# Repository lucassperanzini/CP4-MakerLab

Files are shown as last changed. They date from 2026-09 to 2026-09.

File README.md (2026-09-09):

# Projeto Carrinho — Carrinho"Pokébola"

Projeto de montagem de um carrinho robótico 2WD (duas rodas motorizadas + roda boba), com carenagem esférica impressa em 3D no estilo pokébola.

## Equipe

- Lucas Pisaneschi Speranzini RM98297
- João Pedro de Souza Vieira RM99805

**Laboratório:** Project Maker Lab

## Componentes principais

- ESP32 (controlador)
- Módulo driver de motor L298N
- 2x motor DC com redução 1:48
- Rodas 70x26mm
- Roda boba
- Suporte de pilhas
- Carenagem esférica em PLA (impressa em Bambu Lab A1)
- Chassi em madeira (corte a laser)

---

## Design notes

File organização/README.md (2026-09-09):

# Projeto Carrinho — Carrinho Robótico "Pokébola"

Projeto de montagem de um carrinho robótico 2WD (duas rodas motorizadas + roda boba), com carenagem esférica impressa em 3D no estilo pokébola.

## Equipe

- Lucas
- João

**Laboratório:** Project Maker Lab

## Status atual

- [x] Definição dos requisitos e componentes
- [x] Croqui do chassi
- [x] Carenagem esférica modelada e impressa (base + tampa, encaixe por pressão)
- [x] Chassi interno em madeira (corte a laser) definido
- [x] Diagramas de conexão e alimentação
- [x] MVP, MoSCoW, Backlog, Kanban e planilha de custos definidos
- [ ] Montagem eletrônica completa (ESP32 + L298N + motores)
- [ ] Upload e testes do firmware
- [ ] Testes de locomoção

## Estrutura do repositório

```
├── docs/                          Documentação geral (Parte 1)
│   ├── ficha-requisitos.md
│   ├── croqui-chassi.png
│   ├── mudancas-estrutura-chassi.md
│   ├── conexoes-eletronicas.png
│   ├── diagrama-alimentacao.png
│   └── organizacao-componentes.png
│
├── hardware/                      Parte 2
│   ├── arquitetura/                 imagens e diagramas
│   └── componentes/                 lista-componentes.md
│
├── cad/                            Parte 2
│   ├── STL/
│   │   ├── v0.1/                    primeiro chassi customizado (disco)
│   │   ├── v0.2/                    carenagem oca + colunas internas
│   │   ├── v0.3/                    corte plano + furos das rodas
│   │   └── v0.4-atual/              base + tampa, com encaixe por pressão
│   └── fonte-do-modelo/             scripts Python (trimesh) usados para gerar os STL
│
├── src/                            Parte 2
│   └── codigo.ino                   firmware ESP32 (controle dos motores via L298N)
│
└── organização/                    Planejamento do projeto
    ├── mvp.md                        definição do MVP e da conclusão
    ├── moscow.md                     classificação MoSCoW das funcionalidades
    ├── backlog.md                    tarefas, responsáveis e status
    ├── dependencias.md + .png        mapa de dependências entre tarefas
    ├── kanban.md                     quadro Kanban (snapshot)
    └── planilha-custos.xlsx          custos, lojas, links e quantidades
```

## Documentação (Parte 1)

- [Ficha de Requisitos](./docs/ficha-requisitos.md)
- [Mudanças na estrutura do chassi](./docs/mudancas-estrutura-chassi.md)
- [Conexões dos componentes eletrônicos](./docs/conexoes-eletronicas.png)
- [Diagrama de alimentação](./docs/diagrama-alimentacao.png)
- [Organização dos componentes (fixação e fiação)](./docs/organizacao-componentes.png)

## Organização do projeto

- [MVP — quando estará minimamente funcional / concluído](./organização/mvp.md)
- [Classificação MoSCoW](./organização/moscow.md)
- [Backlog de tarefas](./organização/backlog.md)
- [Mapa de dependências](./organização/dependencias.md)
- [Kanban](./organização/kanban.md)
- [Planilha de custos](./organização/planilha-custos.xlsx)

## Componentes principais

Ver [lista completa](./hardware/componentes/lista-componentes.md) e a [planilha de custos](./organização/planilha-custos.xlsx). Resumo:

- ESP32 (controlador)
- Módulo driver de motor L298N
- 2x motor DC com redução 1:48
- Rodas 70×26mm
- Roda boba
- Suporte de pilhas
- Carenagem esférica em PLA (impressa em Bambu Lab A1)
- Chassi em madeira (corte a laser)

## Modelagem 3D

Os modelos foram gerados de forma paramétrica via scripts Python (biblioteca `trimesh`), no lugar de um software de CAD tradicional (OpenSCAD/Fusion). Os scripts-fonte estão em [`cad/fonte-do-modelo`](./cad/fonte-do-modelo), e os `.stl` versionados em [`cad/STL`](./cad/STL).

## Firmware

Código-fonte em [`src/codigo.ino`](./src/codigo.ino). Pinagem documentada no cabeçalho do arquivo e no [diagrama de conexões](./docs/conexoes-eletronicas.png).

---

*Documentação em construção — próximas atualizações incluirão testes de locomoção e ajustes finais de montagem.*

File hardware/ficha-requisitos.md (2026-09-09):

# Ficha de Requisitos — Carrinho Robótico "Pokébola"

**Projeto:** Carrinho
**Equipe:** Lucas, João
**Turma** 4ESPY
**Disciplina:** Project Maker Lab

---

## 1. Dimensões gerais

| Item | Valor |
|---|---|
| Diâmetro externo da carenagem (esfera) | ~190,5 mm |
| Espessura da parede da carenagem | 6 mm |
| Material da carenagem | PLA (impressão 3D) |
| Altura do corte inferior (para encaixe do chassi) | ~36–40 mm |
| Diâmetro do piso resultante do corte | ~146–150 mm |
| Trilho entre rodas (centro a centro) | 140 mm |
| Diâmetro das rodas | 70 mm |
| Largura das rodas | 26 mm |
| Material do chassi interno | Madeira (corte a laser) |

## 2. Motores

| Item | Especificação |
|---|---|
| Quantidade | 2 |
| Tipo | Motor DC com caixa de redução 1:48 |
| Tensão | 3–6 V |
| Tração | Diferencial (2 rodas motorizadas + 1 roda boba de apoio) |

## 3. Placa controladora e eletrônica

| Componente | Função |
|---|---|
| ESP32 | Controlador principal (lógica, comunicação) |
| Módulo driver L298N | Aciona os motores (ponte H), recebe sinal do ESP32 e energia da bateria |
| Suporte de pilhas | Alimentação do sistema |
| Sensor de Distância | 

## 4. Posição dos componentes

Todos os componentes ficam montados sobre o chassi de madeira, encaixado no piso resultante do corte inferior da carenagem (ver croqui):

- **ESP32**: posição central-frontal do chassi
- **Módulo L298N**: posição central-traseira do chassi
- **Suporte de pilhas**: parte frontal, acima do ESP32
- **Motores DC**: um de cada lado, afastados 70 mm do centro, alinhados aos furos das rodas na carenagem
- **Roda boba**: parte traseira, para equilíbrio do terceiro ponto de apoio

*(posições sujeitas a ajuste fino conforme o layout real da madeira já cortada)*

## 5. Carenagem (cobertura)

- Formato esférico, estilo "pokébola", impressa em duas metades (base + tampa)
- **Base** (metade fixa): contém o corte inferior para o chassi, os furos das rodas e o lábio de encaixe
- **Tampa** (metade removível): contém a ranhura correspondente para o encaixe
- **Método de fechamento**: encaixe por pressão (lábio/ranhura), sem uso de cola — permite abrir para acesso à bateria e eletrônica
- Impressa em impressora Bambu Lab A1 (mesa útil 256×256×256 mm)

## 6. Croqui do chassi

Ver arquivo [`croqui-chassi.png`](./croqui-chassi.png) — vista de cima com posicionamento e cotas.

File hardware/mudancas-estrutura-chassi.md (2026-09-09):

# Mudanças na Estrutura do Chassi

Histórico das decisões de projeto e o motivo de cada mudança.

## v0.1 — Chassi retangular original (kit)
- Kit "Chassi 2 Rodas Base de Acrílico 2WD" (Ref. CF04)
- Base de acrílico 15×21cm, motores DC 1:48, rodas, roda boba
- **Problema:** dimensões grandes demais para caber numa carenagem esférica de tamanho razoável (diagonal de ~26cm exigiria uma esfera de 30cm+)

## v0.2 — Chassi customizado em disco
- Desenhado um chassi circular de 160mm de diâmetro, com furos de fixação para motores, L298N e roda boba
- Objetivo: reduzir o footprint para caber numa esfera menor (~24cm)

## v0.3 — Carenagem esférica oca com colunas internas
- Definido formato "pokébola": duas metades ocas (não maciças), unidas na linha do equador
- Testada a opção de preencher a metade inferior com material sólido → **descartada**: peso estimado de ~9kg, incompatível com o torque dos motores DC 3-6V
- Adotado: casca oca de parede 6mm + colunas de apoio internas para sustentar o chassi
- Carenagem impressa com ~198mm de diâmetro (Bambu Lab A1)

## v0.4 — Corte plano na base + chassi em madeira
- **Mudança de abordagem:** ao invés de um disco de plástico preso por colunas na altura do equador, foi feito um corte plano na parte inferior da esfera (~36–40mm de altura a partir do polo)
- O corte gera um piso plano de ~146–150mm de diâmetro, onde um **chassi de madeira cortado a laser** é encaixado
- **Vantagem:** montagem de motores e componentes fica muito mais simples numa superfície plana do que na parede curva da esfera
- As colunas internas da v0.3 tornaram-se obsoletas e foram removidas do modelo

## v0.5 — Furos das rodas corrigidos
- Verificado que o trilho real entre rodas (140mm) não cabia dentro do buraco central do corte plano (a roda ultrapassava a borda em ~17mm)
- Solução: mantido o buraco central de acesso (para a madeira) e adicionados **2 furos individuais**, um por roda, posicionados exatamente na localização real de cada roda (70mm do centro), cortados na parede curva ao redor do buraco central
- Furos alinhados com o eixo real da roda (não com a direção radial da esfera), eliminando uma pequena interferência residual

## v0.6 — Encaixe por pressão entre as duas metades
- Substituído o encaixe original (peças soltas de dobradiça/botão) por um **lábio de encaixe por pressão** (anel de 2mm) na base, com **ranhura correspondente** na tampa (folga de 0,2mm)
- Permite abrir/fechar sem cola, para acesso à bateria e eletrônica
- A faixa do equador e as peças de botão/dobradiça originais foram fundidas permanentemente na base

## Estado atual
- Base e tampa modeladas e com encaixe validado (0 colisões verificadas)
- Chassi em madeira pronto (corte a laser)
- Próxima etapa: montagem elétrica final e fixação dos componentes na madeira

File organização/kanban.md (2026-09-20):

# Kanban

| 📋 A Fazer | 🔶 Em Andamento | ✅ Concluído |
|---|---|---|
| T05 — Ligar ESP32 → L298N *(Lucas)* | | T01 — Montar chassi de madeira *(Lucas)* |
| T06 — Ligar L298N → motores/bateria *(Lucas)* | | T02 — Modelar/imprimir carenagem *(João)* |
| T07 — Firmware base *(João)* | | T03 — Furos das rodas *(João)* |
| T08 — Testar locomoção *(Lucas + João)* | | T04 — Encaixe base/tampa *(João)* |
| T09 — Fechar e testar na carenagem *(Lucas)* | | |
| T10 — Organizar fiação *(Lucas)* | | |
| T11 — Controle Bluetooth *(João)* | | |
| T12 — Testes de autonomia *(Lucas)* | | |
| T13 — LED de status *(João)* | | |
| T14 — Ajuste PWM *(João)* | | |
| T15 — Acabamento estético *(Lucas)* | | |
| T16 — Documentação final *(Lucas + João)* | | |

**Legenda de responsáveis:** Lucas (montagem mecânica/elétrica) · João (modelagem 3D/firmware) — ver responsabilidades completas no [Backlog](./backlog.md).

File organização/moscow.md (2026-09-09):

# Classificação MoSCoW

| Prioridade | Funcionalidade | Justificativa |
|---|---|---|
| **Must have** | Chassi montado (motores, ESP32, L298N, bateria) | Sem isso não existe carrinho |
| **Must have** | Carenagem fechando (base + tampa) | Requisito estético/estrutural definido no projeto |
| **Must have** | Locomoção básica (frente, trás, girar) via firmware | Núcleo funcional do MVP |
| **Must have** | Alimentação autônoma por bateria | Sem isso o carrinho não é portátil |
| **Should have** | Fiação organizada com abraçadeiras/organizador | Evita curto-circuito e falha mecânica, mas não impede o funcionamento básico |
| **Should have** | Encaixe da tampa testado e confiável (abrir/fechar repetidas vezes) | Importante para manutenção, mas o MVP pode rodar com a tampa presa provisoriamente |
| **Should have** | Controle remoto via Bluetooth (ESP32 já suporta nativamente) | Eleva bastante a usabilidade, mas não é bloqueante pro MVP |
| **Could have** | Indicador visual (LED) de status (ligado/bateria baixa) | Boa prática de UX, mas dispensável |
| **Could have** | Ajuste fino de velocidade via PWM (controle de aceleração suave) | Melhoria de qualidade de movimento |
| **Could have** | Pintura/acabamento estético fiel às cores da pokébola | Estética, não afeta funcionamento |
| **Won't have (por ora)** | Recarga automática / base de carregamento | Fora do escopo |
| **Won't have (por ora)** | Câmera ou sensores de visão | Fora do escopo |

Ver o cruzamento dessas prioridades com o cronograma em [Backlog](./backlog.md) e [Kanban](./kanban.md).

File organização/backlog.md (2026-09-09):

# Backlog

**Divisão de responsabilidades:**
- **Lucas** — software (firmware) e modelagem 3D (CAD)
- **João** — montagem física do chassi e da eletrônica

*(Exceção: LED, sensor de distância e buzzer já foram ligados no ESP32 pelo próprio Lucas — mantidos com ele por ser o que realmente aconteceu.)*

| ID | Tarefa | Responsável | MoSCoW | Depende de | Status |
|---|---|---|---|---|---|
| T01 | Montar chassi de madeira com motores fixados | João | Must | — | ✅ Concluído |
| T02 | Modelar e imprimir carenagem (base + tampa) | Lucas | Must | — | ✅ Concluído |
| T03 | Cortar furos das rodas na carenagem | Lucas | Must | T02 | ✅ Concluído |
| T04 | Projetar e validar encaixe por pressão base/tampa | Lucas | Should | T02 | ✅ Concluído |
| T05 | Ligar ESP32 ao L298N (fiação de sinal) | João | Must | T01 | ⬜ A fazer |
| T06 | Ligar L298N aos motores e à bateria | João | Must | T01, T05 | ⬜ A fazer |
| T07 | Escrever firmware base (andar frente/trás/girar) | Lucas | Must | T05, T06 | ⬜ A fazer |
| T08 | Testar locomoção com a eletrônica solta (fora da carenagem) | Lucas + João | Must | T07 | ⬜ A fazer |
| T09 | Fechar tudo dentro da carenagem e testar encaixe final | João | Must | T04, T08 | ⬜ A fazer |
| T10 | Organizar fiação interna (abraçadeiras/organizador) | João | Should | T06 | ⬜ A fazer |
| T11 | Implementar controle via Bluetooth | Lucas | Should | T07 | ⬜ A fazer |
| T12 | Testes de autonomia de bateria | João | Should | T09 | ⬜ A fazer |
| T13 | Ligar LED indicador de status no ESP32 | Lucas | Could | T05 | ✅ Concluído |
| T14 | Ajuste fino de velocidade (PWM suave) | Lucas | Could | T07 | ⬜ A fazer |
| T15 | Acabamento estético da carenagem (pintura) | João | Could | T09 | ⬜ A fazer |
| T16 | Atualizar documentação final do repositório | Lucas + João | Must | T09, T11 | ⬜ A fazer |
| T17 | Ligar sensor de distância no ESP32 | Lucas | Could | T05 | ✅ Concluído |
| T18 | Ligar buzzer no ESP32 | Lucas | Could | T05 | ✅ Concluído |

**Status usados:** ⬜ A fazer · 🔶 Em andamento · ✅ Concluído

Ver o quadro visual em [Kanban](./kanban.md) e o mapeamento de dependências em [Dependências](./dependencias.md).

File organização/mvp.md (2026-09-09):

# MVP — Produto Mínimo Viável

## Quando o carrinho estará minimamente funcional (MVP)

O MVP é considerado atingido quando:

- [ ] Chassi de madeira montado com os 2 motores, ESP32, L298N e suporte de pilhas fixados
- [ ] Firmware carregado no ESP32 fazendo o carrinho andar para frente, para trás e girar (comando pré-programado, sem controle remoto)
- [ ] Alimentação por bateria funcionando de forma independente (sem precisar de USB conectado ao PC)
- [ ] Rodas tocando o chão corretamente, sem a carenagem raspar no chão

**Em resumo:** o carrinho se movimenta de forma autônoma, fechado dentro da carenagem, mesmo que o "controle" seja só uma sequência de movimentos fixa no código.

## Quando o projeto estará concluído

- [ ] Tudo o que está no MVP, +
- [ ] Alguma forma de controle em tempo real (Bluetooth, Wi-Fi/app, ou controle remoto simples)
- [ ] Fiação interna organizada e presa (abraçadeiras/organizador — ver [organização dos componentes](../docs/organizacao-componentes.png))
- [ ] Encaixe da tampa testado múltiplas vezes sem folga excessiva nem dificuldade de abrir
- [ ] Documentação do repositório completa e atualizada (README, ficha de requisitos, diagramas, backlog)

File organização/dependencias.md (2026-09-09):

# Dependências entre Tarefas

Mapa de dependências

## Caminho crítico (sequência que mais trava o projeto)

```
T01 (chassi) → T05 (ESP32↔L298N) → T06 (L298N↔motores/bateria) → T07 (firmware) → T08 (teste solto) → T09 (fechar na carenagem) → T16 (documentação final)
```

Esse é o caminho que define o prazo mínimo possível: nenhuma tarefa dele pode começar antes da anterior terminar.

## Tarefas que podem rodar em paralelo

- **T02 → T03 → T04** (modelagem/impressão da carenagem) não depende de nada da linha elétrica — pode ser feito ao mesmo tempo que T01, T05, T06
- **T11 (Bluetooth)** só depende do firmware base (T07), não precisa esperar a carenagem estar fechada (T09)
- **T13, T14, T15** (itens "Could have") não bloqueiam nada — podem ficar para o final ou ser cortados sem afetar o restante

## Risco de atraso

O ponto mais sensível é **T09** (fechar tudo dentro da carenagem), porque depende tanto da linha elétrica (T08) quanto da linha mecânica (T04) terminarem. Se uma das duas atrasar, T09 atrasa junto — e com ela, toda a documentação final (T16).

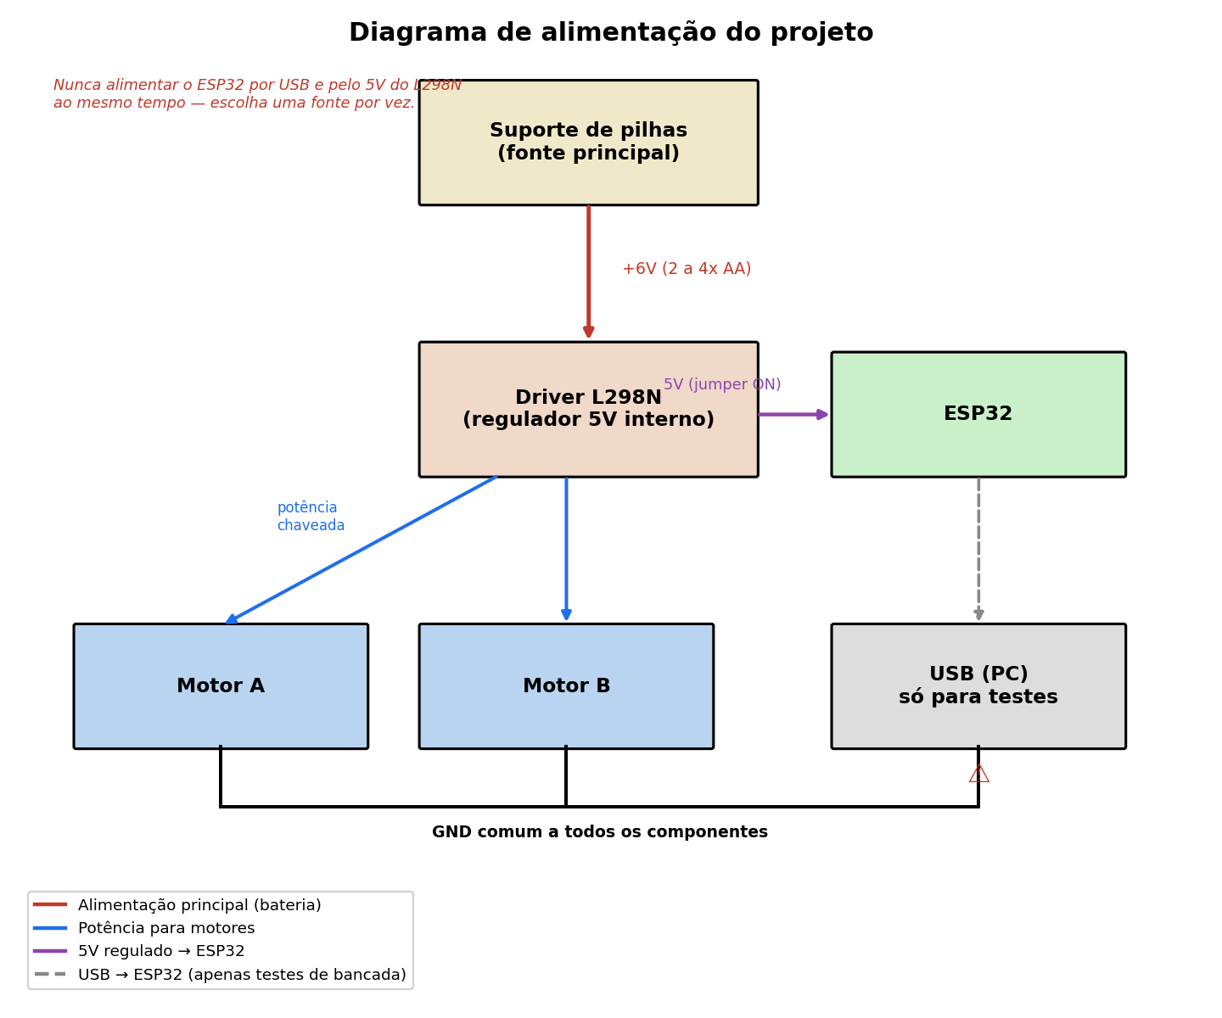
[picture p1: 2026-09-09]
hardware/diagrama-alimentacao.png

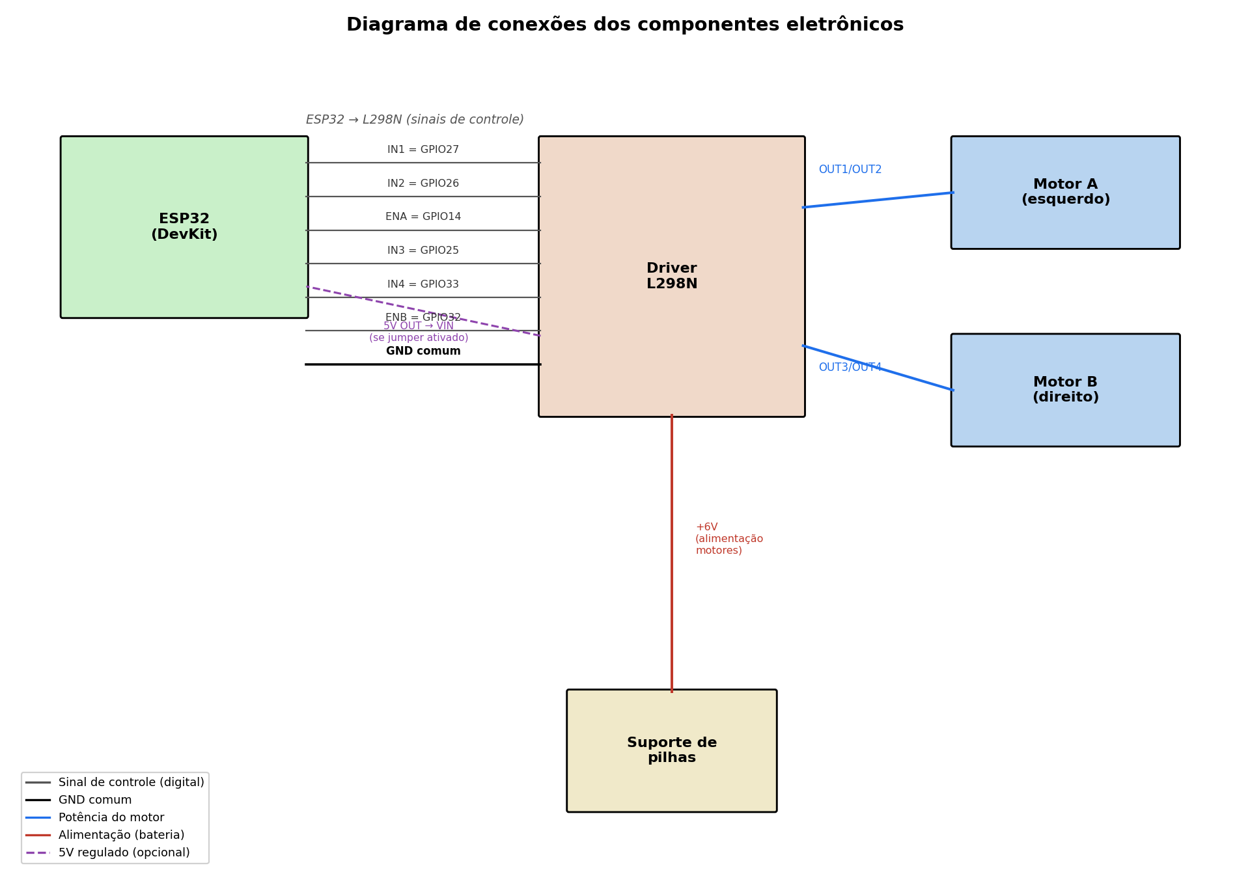
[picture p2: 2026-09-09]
hardware/conexoes-eletronicas.png

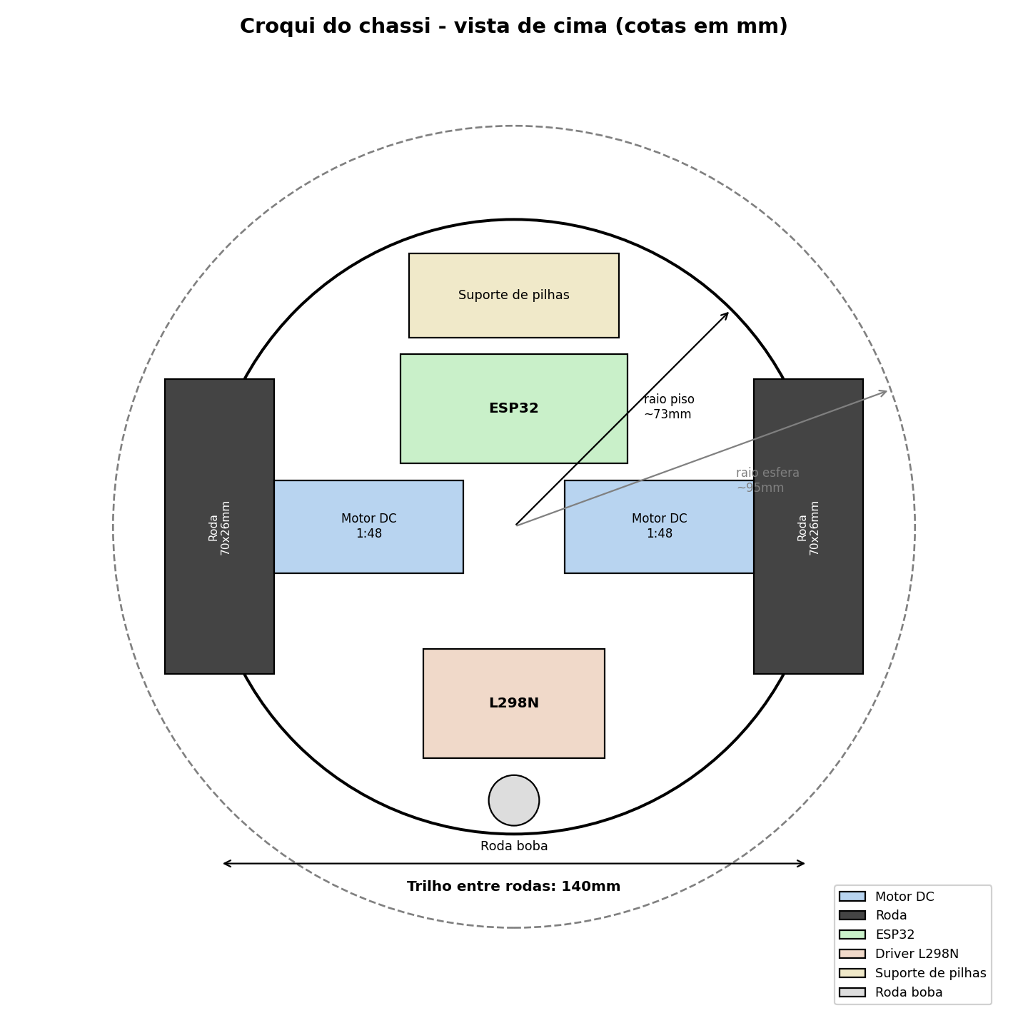
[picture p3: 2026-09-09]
croqui-chassi.png

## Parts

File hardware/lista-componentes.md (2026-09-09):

# Lista de Componentes Utilizados

| # | Componente | Especificação | Quantidade |
|---|---|---|---|
| 1 | Microcontrolador | ESP32 (DevKit) | 1 |
| 2 | Driver de motor | Módulo L298N (ponte H dupla) | 1 |
| 3 | Motor DC | Com caixa de redução 1:48, 3–6V | 2 |
| 4 | Roda | 70mm diâmetro × 26mm largura, borracha | 2 |
| 5 | Roda boba (caster) | Apoio de giro livre | 1 |
| 6 | Suporte de pilhas | Alimentação do sistema | 1 |
| 7 | Chassi interno | Madeira, corte a laser | 1 |
| 8 | Carenagem — base | PLA impresso em 3D (Bambu Lab A1), ~190mm Ø, parede 6mm | 1 |
| 9 | Carenagem — tampa | PLA impresso em 3D (Bambu Lab A1), com ranhura de encaixe | 1 |
| 10 | Cabos/jumpers | Conexão ESP32 ↔ L298N ↔ motores | conforme necessário |
| 11 | Abraçadeiras (zip ties) | Organização e fixação de fios | conforme necessário |

## Origem dos componentes mecânicos
Kit original: "Chassi 2 Rodas Base de Acrílico 2WD + Suporte de Pilhas" (Ref. CF04, Casa da Robótica) — motores, rodas e roda boba reaproveitados do kit; chassi de acrílico original substituído por chassi de madeira sob medida (ver [mudanças na estrutura do chassi](../../docs/mudancas-estrutura-chassi.md)).

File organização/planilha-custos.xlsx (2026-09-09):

Item | Loja | Link | Preço Unit. (R$) | Qtd. | Subtotal (R$) | Observação
ESP32 DevKit (30 pinos) | Saravati | https://www.saravati.com.br/placa-esp32-wifi-bluetooth-devkit-v1-30-pinos.html | R$59.90 | 1 | R$59.90 | Preço confirmado no site em set/2026
Driver Ponte H L298N | LIG Imports | https://www.ligimports.com.br/produto/modulo-ponte-h-l298n/ | R$34.90 | 1 | R$34.90 | Preço confirmado no site em set/2026
Kit Chassi 2 Rodas + Suporte Pilhas (Ref. CF04) | Casa da Robótica | https://www.casadarobotica.com/robotica/chassi-s/carros/kit-chassi-2-rodas | R$59.99 | 1 | R$59.99 | Motores, rodas e roda boba reaproveitados; chassi acrílico substituído pela madeira
Filamento PLA 1kg (para carenagem) | Beehive 3D | https://beehive.com.br/filamentos/ | R$109.90 | 1 | R$109.90 | Usa-se só uma fração do rolo (~300-400g); custo do rolo inteiro listado
Kit Jumpers Macho-Fêmea 40un 20cm | Fermarc | https://www.fermarc.com/kit-jumper-macho-femea-x40-unidades-20cm-para-arduino | R$9.50 | 1 | R$9.50 | Preço confirmado no site em set/2026
Pilhas alcalinas AA (jogo com 4) | Estimado (mercado geral) | https://lista.mercadolivre.com.br/pilha-aa-alcalina | R$14.90 | 1 | R$14.90 | Preço estimado, não coletado de uma página específica
Abraçadeiras de nylon (pacote c/ 100, variadas) | Estimado (mercado geral) | https://lista.mercadolivre.com.br/abracadeira-nylon-kit | R$9.90 | 1 | R$9.90 | Preço estimado, não coletado de uma página específica
Placa de madeira p/ corte a laser (chassi) | Estimado (marcenaria/loja local) | — | R$15.00 | 1 | R$15.00 | Preço estimado; depende do fornecedor de corte a laser usado pela equipe
Parafusos/porcas M3 (kit variado) | Estimado (mercado geral) | https://lista.mercadolivre.com.br/kit-parafuso-m3 | R$12.90 | 1 | R$12.90 | Preço estimado, não coletado de uma página específica
TOTAL ESTIMADO |  |  |  |  | R$326.89
Legenda:
Azul = preço confirmado em loja real (com link)
Azul itálico = preço estimado (sem página específica de origem)
Preços coletados em setembro/2026 — sujeitos a alteração pelas lojas

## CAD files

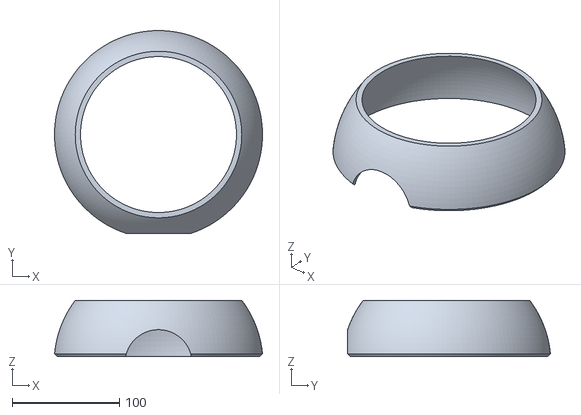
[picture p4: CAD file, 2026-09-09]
stl/baixo.stl
194.2 x 189.4 x 52.7

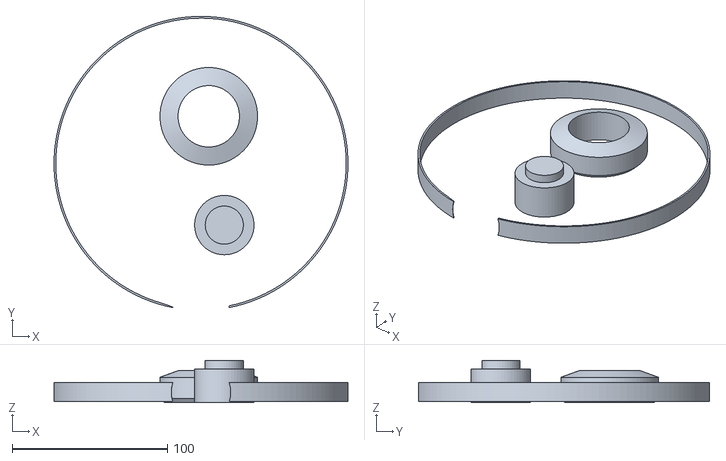
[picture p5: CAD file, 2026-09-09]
stl/Centro.stl
189.1 x 187.4 x 27.3

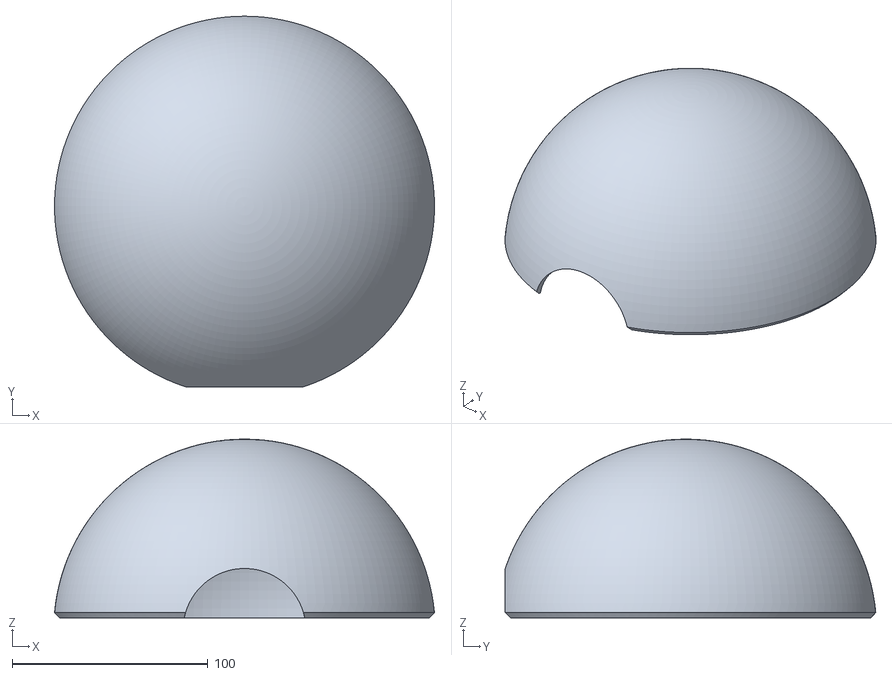
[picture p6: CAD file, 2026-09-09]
stl/cima.stl
194.2 x 189.4 x 91.4

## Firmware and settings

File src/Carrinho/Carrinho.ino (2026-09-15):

#include <BLEDevice.h>
#include <BLEUtils.h>
#include <BLEServer.h>
#include <esp_mac.h>

// Definição dos pinos do sensor ultrassônico e LED
#define TRIG_PIN 5
#define ECHO_PIN 4
#define BUZZER_PIN 18  // Pino do Buzzer
#define LED 2          // Pino do LED azul integrado

// =========================================================================
// MAPEAMENTO DOS PINOS DOS MOTORES (Passe essa lista para o seu amigo!)
// =========================================================================
const int MOTOR_ESQ_1 = 12; // Pino D12 ➔ Entrada IN1 do Driver
const int MOTOR_ESQ_2 = 13; // Pino D13 ➔ Entrada IN2 do Driver
const int MOTOR_DIR_1 = 14; // Pino D14 ➔ Entrada IN3 do Driver
const int MOTOR_DIR_2 = 27; // Pino D27 ➔ Entrada IN4 do Driver

long duracao;
float distancia;

bool tocarMusica = false;

#define SERVICE_UUID        "4FAFC201-1FB5-459E-8FCC-C5C9C331914B"
#define CHARACTERISTIC_UUID "BEB5483E-36E1-4688-B7F5-EA07361B26A8"

BLECharacteristic *pCharacteristic;

// =========================================================================
// FUNÇÕES DE MOVIMENTAÇÃO DO CARRINHO
// =========================================================================
void frente() {
  digitalWrite(MOTOR_ESQ_1, HIGH);  digitalWrite(MOTOR_ESQ_2, LOW);
  digitalWrite(MOTOR_DIR_1, HIGH);  digitalWrite(MOTOR_DIR_2, LOW);
}

void tras() {
  digitalWrite(MOTOR_ESQ_1, LOW);   digitalWrite(MOTOR_ESQ_2, HIGH);
  digitalWrite(MOTOR_DIR_1, LOW);   digitalWrite(MOTOR_DIR_2, HIGH);
}

void esquerda() {
  digitalWrite(MOTOR_ESQ_1, LOW);   digitalWrite(MOTOR_ESQ_2, HIGH); // Roda esquerda para trás
  digitalWrite(MOTOR_DIR_1, HIGH);  digitalWrite(MOTOR_DIR_2, LOW);  // Roda direita para frente
}

void direita() {
  digitalWrite(MOTOR_ESQ_1, HIGH);  digitalWrite(MOTOR_ESQ_2, LOW);  // Roda esquerda para frente
  digitalWrite(MOTOR_DIR_1, LOW);   digitalWrite(MOTOR_DIR_2, HIGH); // Roda direita para trás
}

void parar() {
  digitalWrite(MOTOR_ESQ_1, LOW);   digitalWrite(MOTOR_ESQ_2, LOW);
  digitalWrite(MOTOR_DIR_1, LOW);   digitalWrite(MOTOR_DIR_2, LOW);
}

void efeitoArcadeStart() {
  tone(BUZZER_PIN, 1319, 150); // Nota Mi (E6)
  delay(150);
  tone(BUZZER_PIN, 1568, 150); // Nota Sol (G6)
  delay(150);
  tone(BUZZER_PIN, 2093, 150); // Nota Dó (C7)
  delay(150);
  tone(BUZZER_PIN, 2637, 300); // Nota Mi de novo (E7) - mais longa
  delay(300);
  noTone(BUZZER_PIN);          // Desliga o som
}



// =========================================================================
// LEITURA DE COMANDOS ENVIADOS PELO IPHONE (MAPPED GAMEPAD VIA TEXT)
// =========================================================================
class MyCallbacks: public BLECharacteristicCallbacks {
    void onWrite(BLECharacteristic *pCharacteristic) {
      String value = pCharacteristic->getValue();

      if (value.length() > 0) {
        char comando = value[0]; // Pega a primeira letra enviada pelo app
        
        switch (comando) {
          case 'F': case 'f': frente();   break; // F = Frente
          case 'B': case 'b': tras();     break; // B = Trás (Back)
          case 'L': case 'l': esquerda(); break; // L = Esquerda (Left)
          case 'R': case 'r': direita();  break; // R = Direita (Right)
          case 'S': case 's': parar();    break; // S = Parar (Stop)
          
          // Mantém o teste do LED azul se você quiser piscar para testar
        case '1': 
            digitalWrite(LED, HIGH);
            tocarMusica = true; // Apenas ativa o gatilho, sem travar aqui!
            break;

          case '2': 
            digitalWrite(LED, LOW);
            tocarMusica = false; // Desativa se o comando for recebido
            break;
          
          default: parar(); break;
        }
      }
    }
};

void setup() {
  Serial.begin(115200); // Inicializa a comunicação serial com o computador
  delay(500);           // Pausa para deixar o monitor estável
  
  // Configuração dos Pinos como Saídas e Entradas
  pinMode(LED, OUTPUT);           
  pinMode(TRIG_PIN, OUTPUT);    
  pinMode(ECHO_PIN, INPUT);     
  pinMode(BUZZER_PIN, OUTPUT);  
  
  pinMode(MOTOR_ESQ_1, OUTPUT); pinMode(MOTOR_ESQ_2, OUTPUT);
  pinMode(MOTOR_DIR_1, OUTPUT); pinMode(MOTOR_DIR_2, OUTPUT);
  
  parar(); // Garante que o carrinho comece totalmente parado por segurança

  // Inicialização do Bluetooth BLE
  BLEDevice::init("ESP32_iPhone");
  BLEServer *pServer = BLEDevice::createServer();

  BLEService *pService = pServer->createService(SERVICE_UUID);
  pCharacteristic = pService->createCharacteristic(
                      CHARACTERISTIC_UUID,
                      BLECharacteristic::PROPERTY_READ |
                      BLECharacteristic::PROPERTY_WRITE
                    );

  pCharacteristic->setCallbacks(new MyCallbacks());
  pService->start();

  BLEAdvertising *pAdvertising = BLEDevice::getAdvertising();
  pAdvertising->addServiceUUID(SERVICE_UUID);
  pAdvertising->setScanResponse(true);
  pAdvertising->setMinPreferred(0x06);  
  pAdvertising->setMinPreferred(0x12);
  BLEDevice::startAdvertising();

  Serial.println("ESP32 Inicializado com sucesso! Pronto para o Carrinho 2WD.");
}

void loop() {

  // A execução da música acontece no loop principal
  if (tocarMusica) {
    // fireRed1(BUZZER_PIN,LED);
    // delay(1000);
    // fireRedIntro(BUZZER_PIN,LED);
    // delay(500);
    Hobbit(BUZZER_PIN,LED);
    delay(1000);

    efeitoArcadeStart();
    
    tocarMusica = false; // Desliga o gatilho ao terminar a música


    delay(200);
    digitalWrite(LED, LOW);
      delay(100);
    digitalWrite(LED, HIGH);
      delay(200);
        digitalWrite(LED, LOW);
           delay(200);
        digitalWrite(LED, HIGH);

  }
  // =========================================================================
  // LEITURA DO SENSOR ULTRASSÔNICO E BUZZER
  // =========================================================================
  digitalWrite(TRIG_PIN, LOW);
  delayMicroseconds(2);
  digitalWrite(TRIG_PIN, HIGH);
  delayMicroseconds(10);
  digitalWrite(TRIG_PIN, LOW);

  // CORREÇÃO: Adicionado timeout de 20000ms para o sensor não congelar a recepção do Bluetooth
  duracao = pulseIn(ECHO_PIN, HIGH, 20000); 
  distancia = duracao * 0.034 / 2;

  // Mostra os valores obtidos no Monitor Serial do Windows

  if(distancia != 0){
    Serial.print("Distancia: ");
    Serial.print(distancia);
    Serial.println(" cm");

  }


  // Alerta de proximidade do obstáculo (Garante o aviso e proteção)
  if (distancia > 0 && distancia <= 5) {
    Serial.println("TA PERTO");
    tone(BUZZER_PIN, 3000); 
    
    // SISTEMA DE SEGURANÇA ANTIBATIDA:
    // Se o sensor detectar algo menor ou igual a 5cm, força o carrinho a PARAR
    parar(); 
  } else {
    noTone(BUZZER_PIN);     
  }

  delay(50); // Delay ideal para leitura contínua e manter os controles rápidos
}

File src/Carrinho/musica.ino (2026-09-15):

/* 
  Super Mario Bros - Overworld theme 
  Connect a piezo buzzer or speaker to pin 11 or select a new pin.
  More songs available at https://github.com/robsoncouto/arduino-songs                                            
                                              
                                              Robson Couto, 2019
*/

#define NOTE_B0  31
#define NOTE_C1  33
#define NOTE_CS1 35
#define NOTE_D1  37
#define NOTE_DS1 39
#define NOTE_E1  41
#define NOTE_F1  44
#define NOTE_FS1 46
#define NOTE_G1  49
#define NOTE_GS1 52
#define NOTE_A1  55
#define NOTE_AS1 58
#define NOTE_B1  62
#define NOTE_C2  65
#define NOTE_CS2 69
#define NOTE_D2  73
#define NOTE_DS2 78
#define NOTE_E2  82
#define NOTE_F2  87
#define NOTE_FS2 93
#define NOTE_G2  98
#define NOTE_GS2 104
#define NOTE_A2  110
#define NOTE_AS2 117
#define NOTE_B2  123
#define NOTE_C3  131
#define NOTE_CS3 139
#define NOTE_D3  147
#define NOTE_DS3 156
#define NOTE_E3  165
#define NOTE_F3  175
#define NOTE_FS3 185
#define NOTE_G3  196
#define NOTE_GS3 208
#define NOTE_A3  220
#define NOTE_AS3 233
#define NOTE_B3  247
#define NOTE_C4  262
#define NOTE_CS4 277
#define NOTE_D4  294
#define NOTE_DS4 311
#define NOTE_E4  330
#define NOTE_F4  349
#define NOTE_FS4 370
#define NOTE_G4  392
#define NOTE_GS4 415
#define NOTE_A4  440
#define NOTE_AS4 466
#define NOTE_B4  494
#define NOTE_C5  523
#define NOTE_CS5 554
#define NOTE_D5  587
#define NOTE_DS5 622
#define NOTE_E5  659
#define NOTE_F5  698
#define NOTE_FS5 740
#define NOTE_G5  784
#define NOTE_GS5 831
#define NOTE_A5  880
#define NOTE_AS5 932
#define NOTE_B5  988
#define NOTE_C6  1047
#define NOTE_CS6 1109
#define NOTE_D6  1175
#define NOTE_DS6 1245
#define NOTE_E6  1319
#define NOTE_F6  1397
#define NOTE_FS6 1480
#define NOTE_G6  1568
#define NOTE_GS6 1661
#define NOTE_A6  1760
#define NOTE_AS6 1865
#define NOTE_B6  1976
#define NOTE_C7  2093
#define NOTE_CS7 2217
#define NOTE_D7  2349
#define NOTE_DS7 2489
#define NOTE_E7  2637
#define NOTE_F7  2794
#define NOTE_FS7 2960
#define NOTE_G7  3136
#define NOTE_GS7 3322
#define NOTE_A7  3520
#define NOTE_AS7 3729
#define NOTE_B7  3951
#define NOTE_C8  4186
#define NOTE_CS8 4435
#define NOTE_D8  4699
#define NOTE_DS8 4978
#define REST      0


// change this to make the song slower or faster
int tempo = 200;



// notes of the moledy followed by the duration.
// a 4 means a quarter note, 8 an eighteenth , 16 sixteenth, so on
// !!negative numbers are used to represent dotted notes,
// so -4 means a dotted quarter note, that is, a quarter plus an eighteenth!!
int melody[] = {

  // Super Mario Bros theme
  // Score available at https://musescore.com/user/2123/scores/2145
  // Theme by Koji Kondo
  
  
  NOTE_E5,8, NOTE_E5,8, REST,8, NOTE_E5,8, REST,8, NOTE_C5,8, NOTE_E5,8, //1
  NOTE_G5,4, REST,4, NOTE_G4,8, REST,4, 
  NOTE_C5,-4, NOTE_G4,8, REST,4, NOTE_E4,-4, // 3
  NOTE_A4,4, NOTE_B4,4, NOTE_AS4,8, NOTE_A4,4,
  NOTE_G4,-8, NOTE_E5,-8, NOTE_G5,-8, NOTE_A5,4, NOTE_F5,8, NOTE_G5,8,
  REST,8, NOTE_E5,4,NOTE_C5,8, NOTE_D5,8, NOTE_B4,-4,
  NOTE_C5,-4, NOTE_G4,8, REST,4, NOTE_E4,-4, // repeats from 3
  NOTE_A4,4, NOTE_B4,4, NOTE_AS4,8, NOTE_A4,4,
  NOTE_G4,-8, NOTE_E5,-8, NOTE_G5,-8, NOTE_A5,4, NOTE_F5,8, NOTE_G5,8,
  REST,8, NOTE_E5,4,NOTE_C5,8, NOTE_D5,8, NOTE_B4,-4,

  
  REST,4, NOTE_G5,8, NOTE_FS5,8, NOTE_F5,8, NOTE_DS5,4, NOTE_E5,8,//7
  REST,8, NOTE_GS4,8, NOTE_A4,8, NOTE_C4,8, REST,8, NOTE_A4,8, NOTE_C5,8, NOTE_D5,8,
  REST,4, NOTE_DS5,4, REST,8, NOTE_D5,-4,
  NOTE_C5,2, REST,2,

  REST,4, NOTE_G5,8, NOTE_FS5,8, NOTE_F5,8, NOTE_DS5,4, NOTE_E5,8,//repeats from 7
  REST,8, NOTE_GS4,8, NOTE_A4,8, NOTE_C4,8, REST,8, NOTE_A4,8, NOTE_C5,8, NOTE_D5,8,
  REST,4, NOTE_DS5,4, REST,8, NOTE_D5,-4,
  NOTE_C5,2, REST,2,

  NOTE_C5,8, NOTE_C5,4, NOTE_C5,8, REST,8, NOTE_C5,8, NOTE_D5,4,//11
  NOTE_E5,8, NOTE_C5,4, NOTE_A4,8, NOTE_G4,2,

  NOTE_C5,8, NOTE_C5,4, NOTE_C5,8, REST,8, NOTE_C5,8, NOTE_D5,8, NOTE_E5,8,//13
  REST,1, 
  NOTE_C5,8, NOTE_C5,4, NOTE_C5,8, REST,8, NOTE_C5,8, NOTE_D5,4,
  NOTE_E5,8, NOTE_C5,4, NOTE_A4,8, NOTE_G4,2,
  NOTE_E5,8, NOTE_E5,8, REST,8, NOTE_E5,8, REST,8, NOTE_C5,8, NOTE_E5,4,
  NOTE_G5,4, REST,4, NOTE_G4,4, REST,4, 
  NOTE_C5,-4, NOTE_G4,8, REST,4, NOTE_E4,-4, // 19
  
  NOTE_A4,4, NOTE_B4,4, NOTE_AS4,8, NOTE_A4,4,
  NOTE_G4,-8, NOTE_E5,-8, NOTE_G5,-8, NOTE_A5,4, NOTE_F5,8, NOTE_G5,8,
  REST,8, NOTE_E5,4, NOTE_C5,8, NOTE_D5,8, NOTE_B4,-4,

  NOTE_C5,-4, NOTE_G4,8, REST,4, NOTE_E4,-4, // repeats from 19
  NOTE_A4,4, NOTE_B4,4, NOTE_AS4,8, NOTE_A4,4,
  NOTE_G4,-8, NOTE_E5,-8, NOTE_G5,-8, NOTE_A5,4, NOTE_F5,8, NOTE_G5,8,
  REST,8, NOTE_E5,4, NOTE_C5,8, NOTE_D5,8, NOTE_B4,-4,

  NOTE_E5,8, NOTE_C5,4, NOTE_G4,8, REST,4, NOTE_GS4,4,//23
  NOTE_A4,8, NOTE_F5,4, NOTE_F5,8, NOTE_A4,2,
  NOTE_D5,-8, NOTE_A5,-8, NOTE_A5,-8, NOTE_A5,-8, NOTE_G5,-8, NOTE_F5,-8,
  
  NOTE_E5,8, NOTE_C5,4, NOTE_A4,8, NOTE_G4,2, //26
  NOTE_E5,8, NOTE_C5,4, NOTE_G4,8, REST,4, NOTE_GS4,4,
  NOTE_A4,8, NOTE_F5,4, NOTE_F5,8, NOTE_A4,2,
  NOTE_B4,8, NOTE_F5,4, NOTE_F5,8, NOTE_F5,-8, NOTE_E5,-8, NOTE_D5,-8,
  NOTE_C5,8, NOTE_E4,4, NOTE_E4,8, NOTE_C4,2,

  NOTE_E5,8, NOTE_C5,4, NOTE_G4,8, REST,4, NOTE_GS4,4,//repeats from 23
  NOTE_A4,8, NOTE_F5,4, NOTE_F5,8, NOTE_A4,2,
  NOTE_D5,-8, NOTE_A5,-8, NOTE_A5,-8, NOTE_A5,-8, NOTE_G5,-8, NOTE_F5,-8,
  
  NOTE_E5,8, NOTE_C5,4, NOTE_A4,8, NOTE_G4,2, //26
  NOTE_E5,8, NOTE_C5,4, NOTE_G4,8, REST,4, NOTE_GS4,4,
  NOTE_A4,8, NOTE_F5,4, NOTE_F5,8, NOTE_A4,2,
  NOTE_B4,8, NOTE_F5,4, NOTE_F5,8, NOTE_F5,-8, NOTE_E5,-8, NOTE_D5,-8,
  NOTE_C5,8, NOTE_E4,4, NOTE_E4,8, NOTE_C4,2,
  NOTE_C5,8, NOTE_C5,4, NOTE_C5,8, REST,8, NOTE_C5,8, NOTE_D5,8, NOTE_E5,8,
  REST,1,

  NOTE_C5,8, NOTE_C5,4, NOTE_C5,8, REST,8, NOTE_C5,8, NOTE_D5,4, //33
  NOTE_E5,8, NOTE_C5,4, NOTE_A4,8, NOTE_G4,2,
  NOTE_E5,8, NOTE_E5,8, REST,8, NOTE_E5,8, REST,8, NOTE_C5,8, NOTE_E5,4,
  NOTE_G5,4, REST,4, NOTE_G4,4, REST,4, 
  NOTE_E5,8, NOTE_C5,4, NOTE_G4,8, REST,4, NOTE_GS4,4,
  NOTE_A4,8, NOTE_F5,4, NOTE_F5,8, NOTE_A4,2,
  NOTE_D5,-8, NOTE_A5,-8, NOTE_A5,-8, NOTE_A5,-8, NOTE_G5,-8, NOTE_F5,-8,
  
  NOTE_E5,8, NOTE_C5,4, NOTE_A4,8, NOTE_G4,2, //40
  NOTE_E5,8, NOTE_C5,4, NOTE_G4,8, REST,4, NOTE_GS4,4,
  NOTE_A4,8, NOTE_F5,4, NOTE_F5,8, NOTE_A4,2,
  NOTE_B4,8, NOTE_F5,4, NOTE_F5,8, NOTE_F5,-8, NOTE_E5,-8, NOTE_D5,-8,
  NOTE_C5,8, NOTE_E4,4, NOTE_E4,8, NOTE_C4,2,
  
  //game over sound
  NOTE_C5,-4, NOTE_G4,-4, NOTE_E4,4, //45
  NOTE_A4,-8, NOTE_B4,-8, NOTE_A4,-8, NOTE_GS4,-8, NOTE_AS4,-8, NOTE_GS4,-8,
  NOTE_G4,8, NOTE_D4,8, NOTE_E4,-2,  

};

// sizeof gives the number of bytes, each int value is composed of two bytes (16 bits)
// there are two values per note (pitch and duration), so for each note there are four bytes
int notes = sizeof(melody) / sizeof(melody[0]) / 2;

// this calculates the duration of a whole note in ms
int wholenote = (60000 * 4) / tempo;

int divider = 0, noteDuration = 0;
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
